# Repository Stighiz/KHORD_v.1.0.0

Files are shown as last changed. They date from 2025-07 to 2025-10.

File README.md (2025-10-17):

# KHORD_v.1.0.0
KHORD è una tastiera stenografica digitale open-source, a basso costo e personalizzabile, pensata per studenti, scrittori, programmatori e hobbisti, oltre che per professionisti.

FOTO KHORD

Progettata da zero, include un hardware ottimizzato per la stenografia a due mani e un firmware in C per il microcontrollore ESP32-S3, il quale non è supportato dai firmware open-source esistenti (es. QMK).

La repository è organizzata in 4 cartelle:  
- `Hardware/`: schema elettrico, layout PCB, modello 3D del case, file Gerber  
- `Software/`: firmware in C (ESP-IDF) per gestione matrice, debouncing, protocollo GeminiPR, comunicazione USB con Plover 4.0.1
- `Case/`: file per la stampa 3D del case 
- `Documentazione/`: presentazione di KHORD + relazione tecnica con descrizione dettagliata dell'intero progetto e appendici sull'organizzazione dei file hardware e software, sui i metodi principali contenuti e sulle loro funzioni. 

A [questo link](https://www.typination.com/ploversteno) è disponibie un dizionario da inglese a steno, utile per imparare gli accordi stenografici.

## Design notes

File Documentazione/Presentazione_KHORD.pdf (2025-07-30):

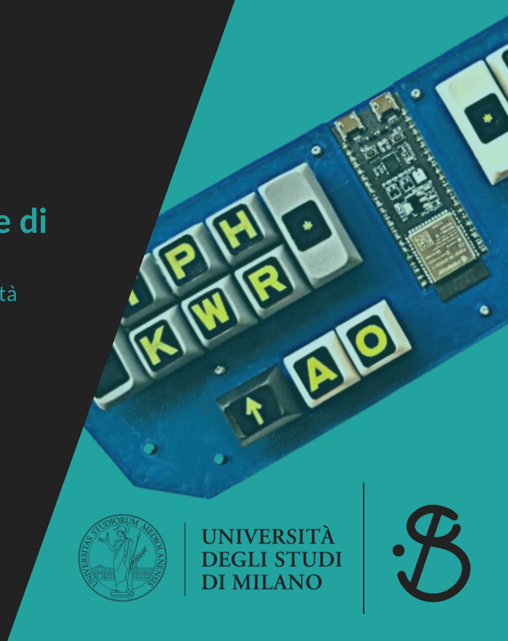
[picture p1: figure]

## KHORD: Progettazione e Realizzazione di una Tastiera Stenografica Digitale

Dipartimento di Informatica ”Giovanni degli Antoni”, Universita`

degli Studi di Milano

Valeria Stighezza e Marco Barbaro

Luglio 2025

## Indice

1 Introduzione

- Introduzione
- Progettazione Hardware
- Progettazione Software
- Analisi e Conclusioni

## Stenografia e Tastiere Stenografiche

1 Introduzione

Le Tastiere Stenografiche

- Stenografia = trascrizione testuale in tempo reale
- Tastiera stenografica divisa in: consonanti iniziali / vocali / consonanti finali
- Non tutte le lettere sono presenti (es. C), alcune sono ripetute (es. T)
- Input fonetico tramite accordi: pressione simultanea di piu tasti ( ` | chords)

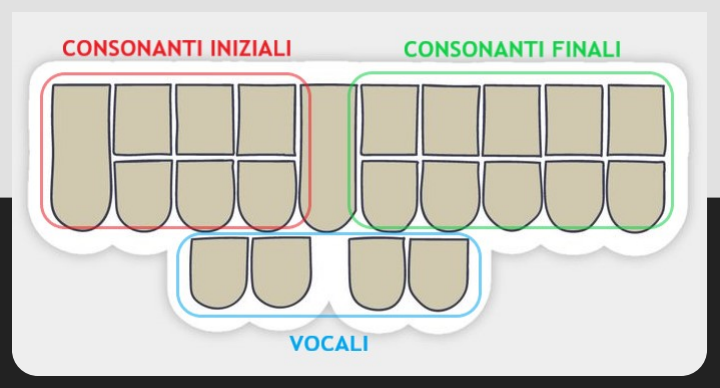
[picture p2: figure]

- Accordi: sillabe o intere parole
- Esempi: ”cat” → KAT, ”chord” → KHORD
- Velocita:` 200+ WPM (al posto di 50-80)

## Tastiere Meccaniche e Obiettivi del Progetto

1 Introduzione

Le Tastiere Meccaniche
- Interruttori meccanici individuali sotto a ogni tasto
- Vantaggi: durata, N-key rollover, anti-ghosting, personalizzazione (es. QMK), facile manutenzione

Obiettivi e Motivazioni del progetto

- Superare limiti di QMK su ESP32-S3 (non compatibile!!)
- Firmware dedicato + hardware su misura
- Tastiera a basso costo e open-source → accessibile e replicabile
- Pensata per chiunque: studenti, programmatori, scrittori, professionisti ...

## Indice

2 Progettazione Hardware

- Introduzione
- Progettazione Hardware
- Progettazione Software
- Analisi e Conclusioni

## Componentistica

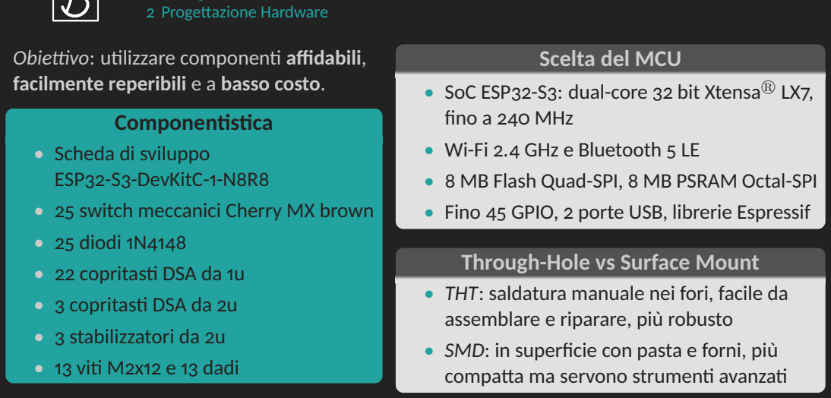
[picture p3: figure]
2 Progettazione Hardware; Obiettivo: utilizzare componenti affidabili, facilmente reperibili e a basso costo.; Componentistica; • Scheda di sviluppo; ESP32-S3-DevKitC-1-N8R8; • 25 switch meccanici Cherry MX brown; • 25 diodi 1N4148; • 22 copritasti DSA da 1u; • 3 copritasti DSA da 2u; • 3 stabilizzatori da 2u; • 13 viti M2x12 e 13 dadi; Scelta del MCU; fino a 240 MHz; • Wi-Fi 2.4 GHz e Bluetooth 5 LE; Through-Hole vs Surface Mount; assemblare e riparare, piu robusto `; compatta ma servono strumenti avanzati

- SoC ESP32-S3: dual-core 32 bit Xtensa® LX7,
- 8 MB Flash Quad-SPI, 8 MB PSRAM Octal-SPI
- Fino 45 GPIO, 2 porte USB, librerie Espressif
- THT: saldatura manuale nei fori, facile da
- SMD: in superficie con pasta e forni, piu`

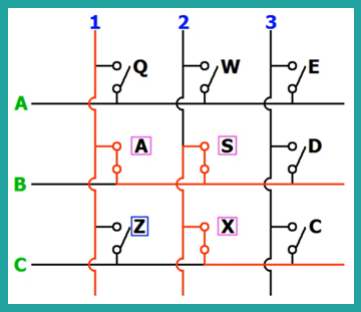
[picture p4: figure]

## Gestione Affidabile dell’Input

2 Progettazione Hardware

Obiettivo: garantire l’affidabilita della tastiera anche con ` pressioni multiple simultanee.

Ghosting - senza Diodi
- Piu tasti premuti ` | → percorsi elettrici indesiderati
- Il microcontrollore registra tasti mai premuti (es. Z)

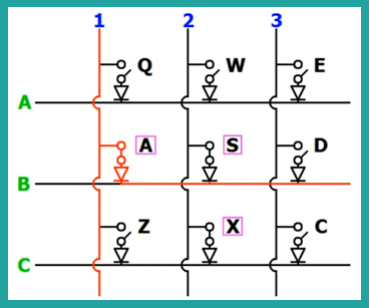
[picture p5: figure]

| Blocking - con Diodi
- Ogni tasto ha un diodo in serie: corrente solo dalla colonna alla riga (no percorsi inversi → no ghosting)
| N-Key Rollover
- Grazie ai diodi, ogni tasto e` indipendente e rilevabile simultaneamente

## Progettazione Circuito Stampato - Schema Elettrico

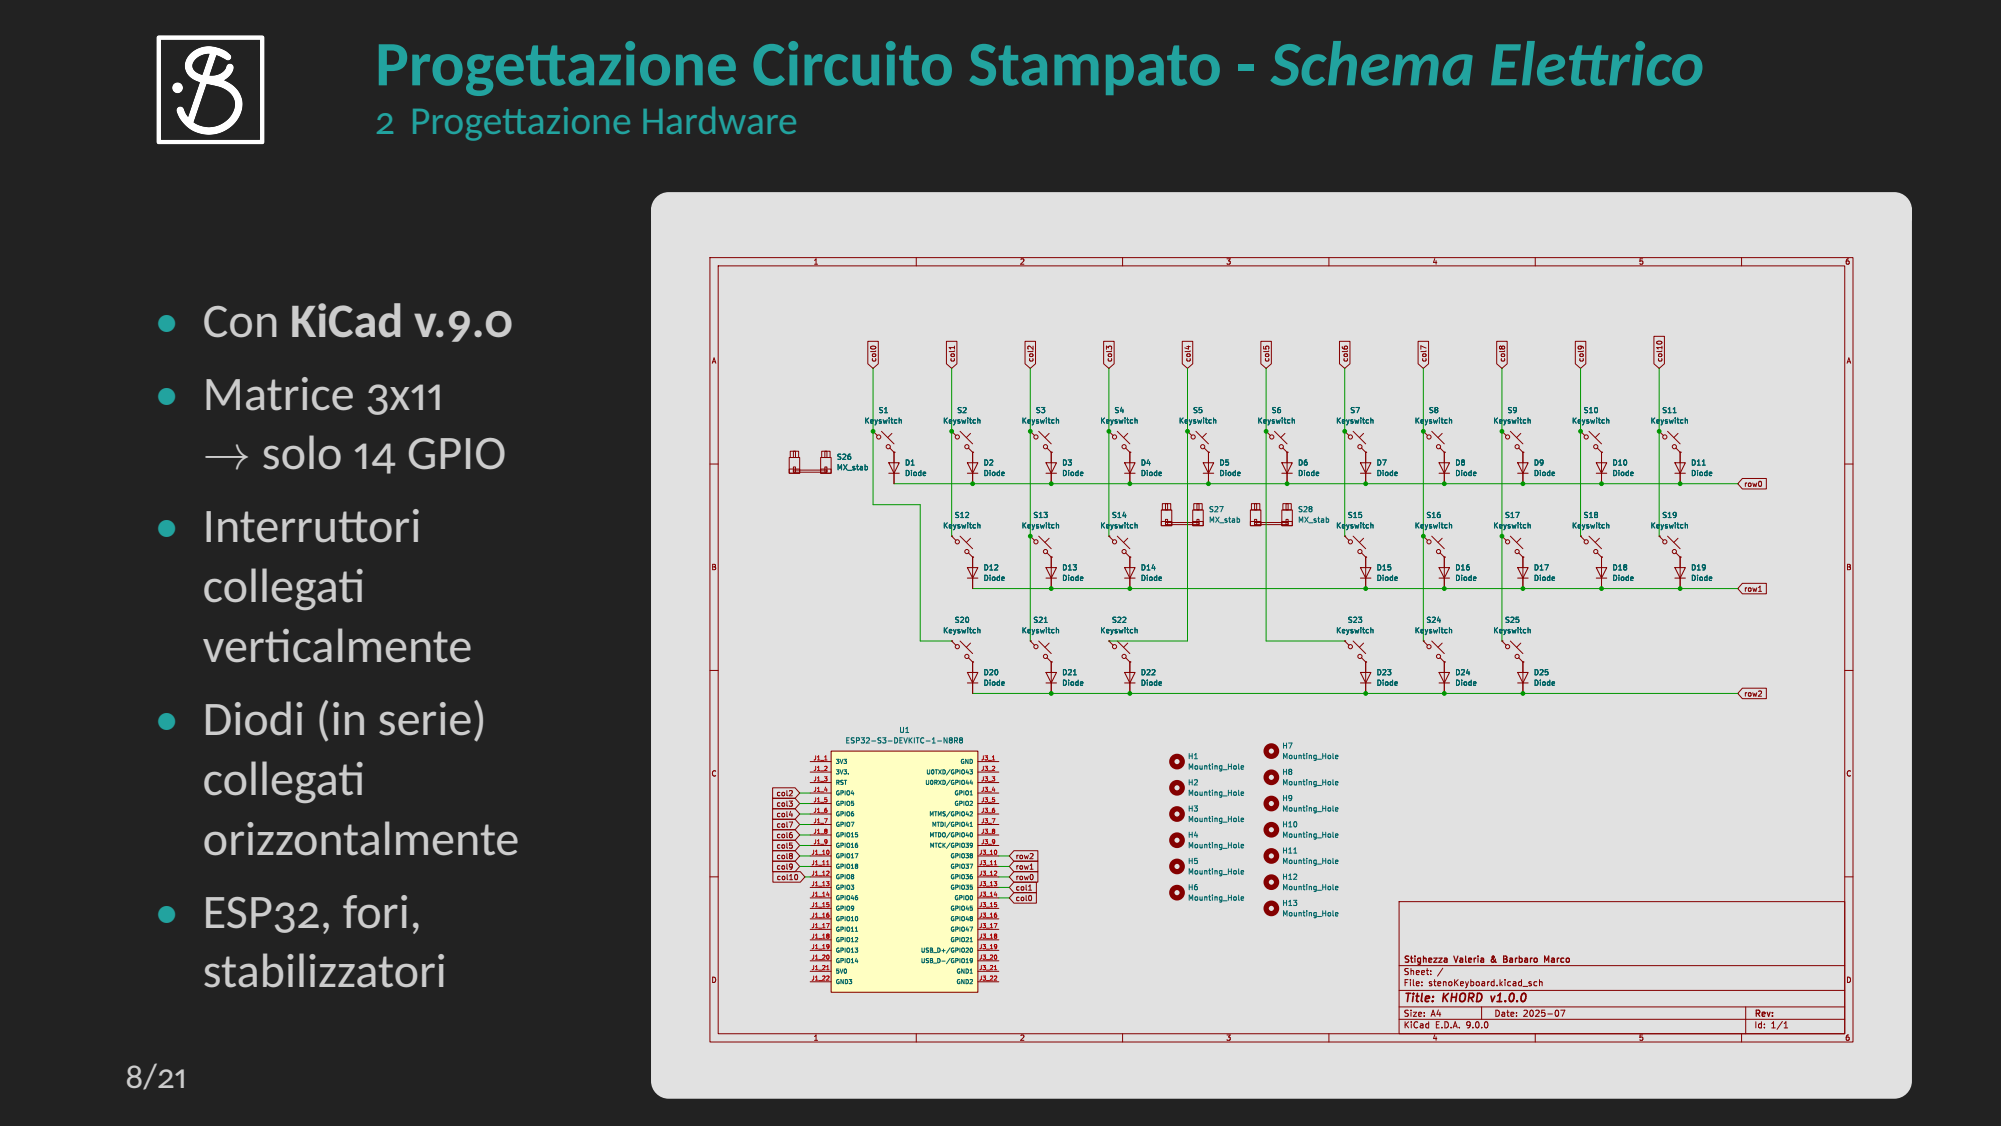
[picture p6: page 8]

## Progettazione Circuito Stampato - Layout

2 Progettazione Hardware

- Interruttori, ESP32 e stabilizzatori su F.Cu; diodi su B.Cu
- Routing: colonne su B.Cu, righe su F.Cu; vias usati per incroci, tracce da 0.5 mm (min. dist. 1 mm), angoli 90° evitati
- Serigrafia include logo personalizzato
- Zone di rame <no net>: migliorano dissipazione, isolamento e robustezza

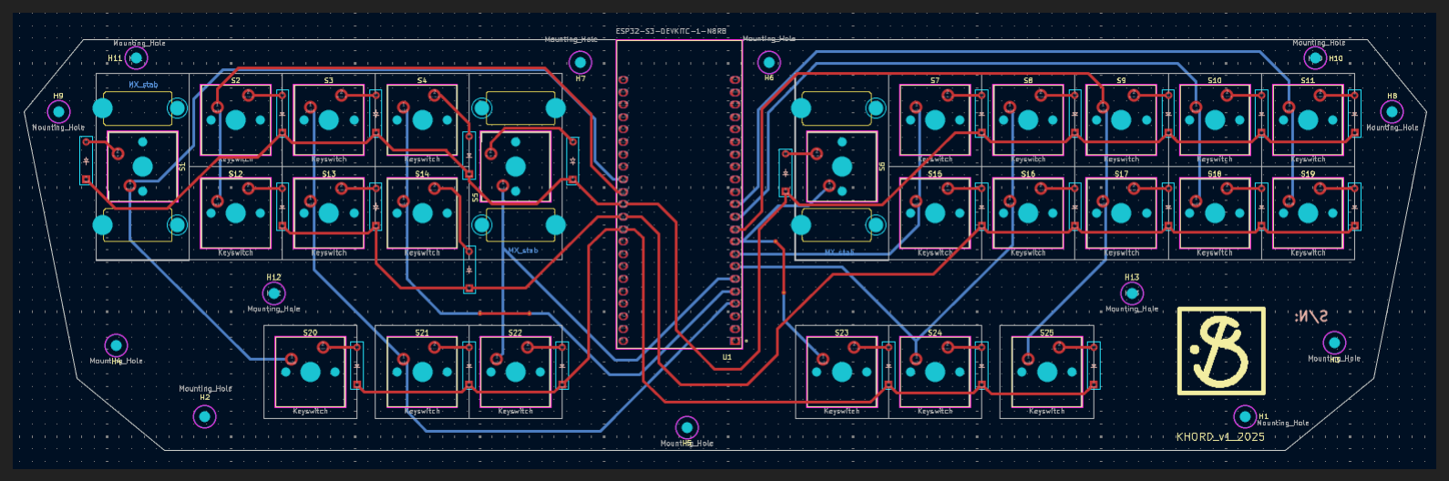
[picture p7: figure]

## Progettazione Circuito Stampato - Modello 3D

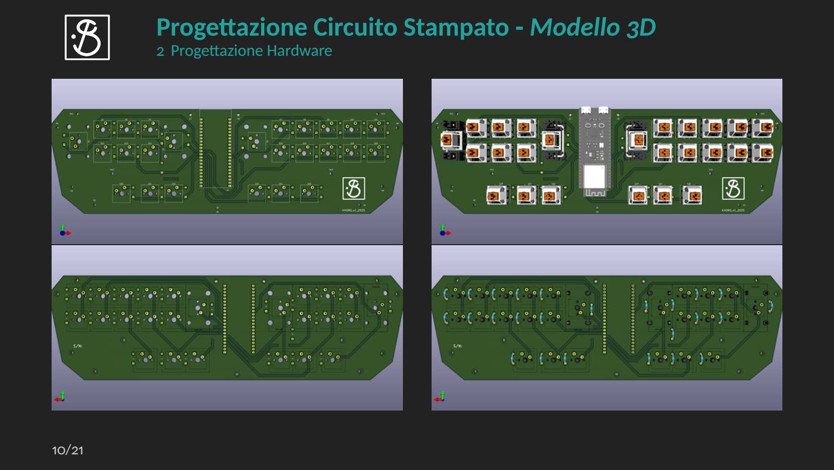
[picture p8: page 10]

2 Progettazione Hardware

## Produzione PCB e Case 3D

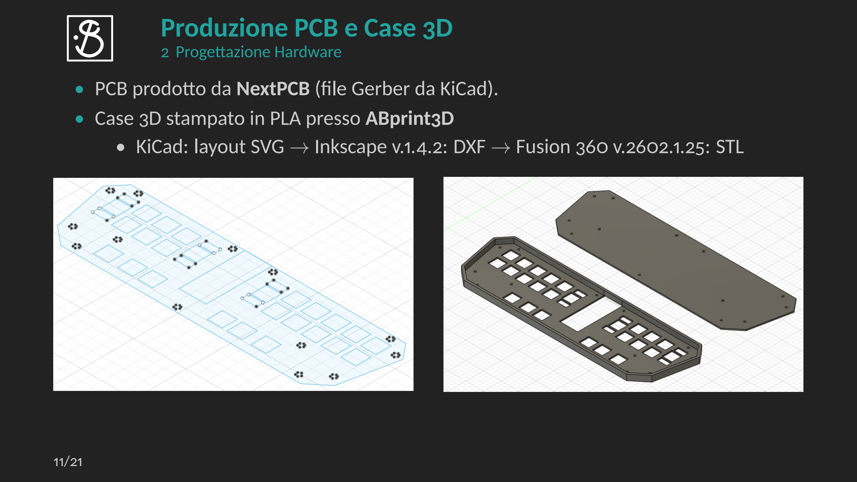
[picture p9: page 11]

2 Progettazione Hardware

- PCB prodotto da NextPCB (file Gerber da KiCad).
- Case 3D stampato in PLA presso ABprint3D
- KiCad: layout SVG → Inkscape v.1.4.2: DXF → Fusion 360 v.2602.1.25: STL

## Saldatura dei Componenti (THT)

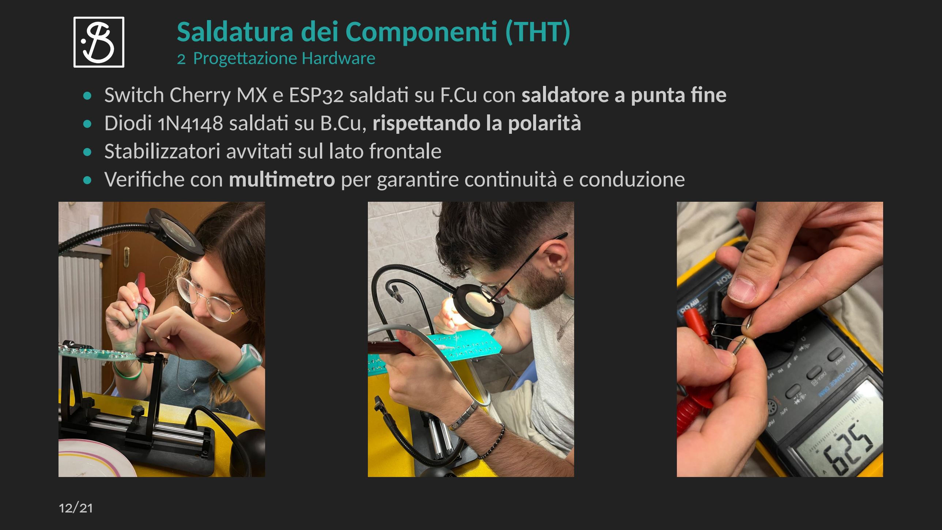
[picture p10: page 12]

2 Progettazione Hardware

- Switch Cherry MX e ESP32 saldati su F.Cu con saldatore a punta fine
- Diodi 1N4148 saldati su B.Cu, rispettando la polarita`
- Stabilizzatori avvitati sul lato frontale
- Verifiche con multimetro per garantire continuita e conduzione `

## Montaggio Finale e Risultato

2 Progettazione Hardware

- Con viti M2 e dadi: top case con PCB + bottom case
- Test funzionali completati: stabilita meccanica e circuitale `

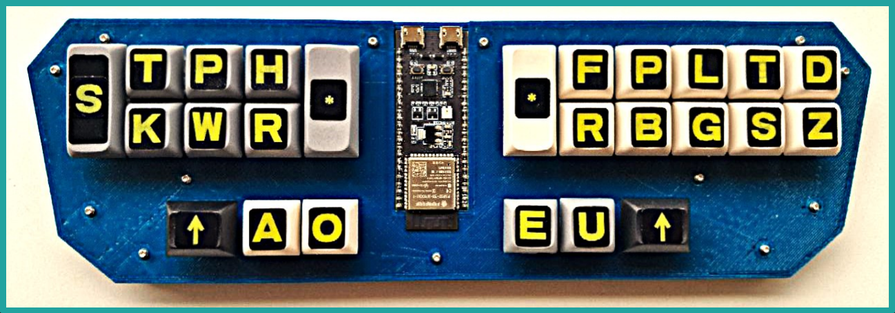
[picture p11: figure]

## Indice

3 Progettazione Software

- Introduzione
- Progettazione Hardware
- Progettazione Software
- Analisi e Conclusioni

## Pipeline di Sviluppo Firmware

3 Progettazione Software

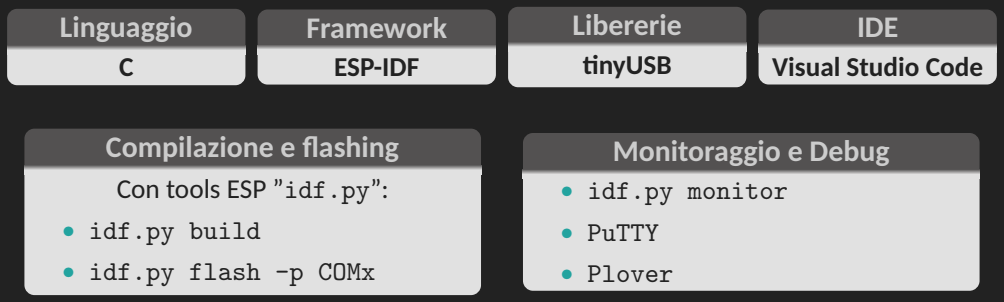
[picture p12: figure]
Linguaggio; Framework; ESP-IDF; Libererie; tinyUSB; IDE; Visual Studio Code; Compilazione e flashing; Con tools ESP ”idf.py”:; • idf.py build; • idf.py flash -p COMx; Monitoraggio e Debug; • idf.py monitor; • PuTTY; • Plover

## Scansione della Matrice e Debouncing

3 Progettazione Software

- Matrice fisica 3x11 gestita via GPIO
- Rappresentata come array di uint16 t dove ogni cella e una riga e ogni bit ` | e`
una colonna
- Doppia matrice:
- RAW: stato diretto della tastiera
- FILTRATA: stato stabile post-debounce
- Matrix Scan ogni 3ms
- Innescato da interrupt HW GPTimer
- Deferred work: ISR minimale e gestione nel main
- Debounce software timing-based di 10ms

## Protocollo di Chording e Plover

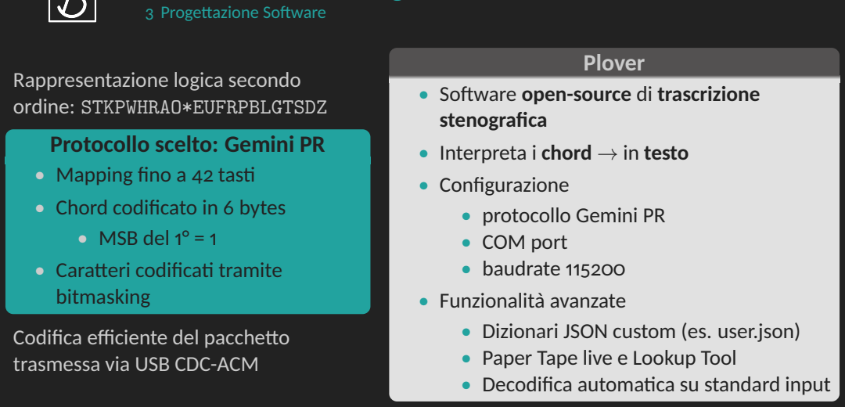
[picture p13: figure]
3 Progettazione Software; Rappresentazione logica secondo; ordine: STKPWHRAO*EUFRPBLGTSDZ; Protocollo scelto: Gemini PR; • Mapping fino a 42 tasti; • Chord codificato in 6 bytes; • MSB del 1° = 1; • Caratteri codificati tramite; bitmasking; Codifica efficiente del pacchetto; trasmessa via USB CDC-ACM; Plover; • Software open-source di trascrizione stenografica; • Interpreta i chord → in testo; • Configurazione; • protocollo Gemini PR; • COM port • baudrate 115200; • Funzionalita avanzate `; • Dizionari JSON custom (es. user.json); • Paper Tape live e Lookup Tool

- Decodifica automatica su standard input

## Indice

4 Analisi e Conclusioni

- Introduzione
- Progettazione Hardware
- Progettazione Software
- Analisi e Conclusioni

## Analisi e Valutazioni

4 Analisi e Conclusioni

Potenza Dissipata

- Inferiore a 0.1 W anche in presenza di input ad alta intensita`

Prestazioni (Tempi di Esecuzione)

- Tscan = 99µs, ogni 3 ms → circa 2.9 ms liberi per le operazioni asincrone
- Ttrasmissione = 520µs → reattivita elevata anche con input intenso `

Costo in e

- Costo Pezzi Utilizzati: 32.24 e
- Costo Totale Acquisto in Blocco: 66.24 e
- + 40 e per il case (il prezzo dipende dalla disponibilita di una stampante 3D) `

## Conclusioni e Sviluppi Futuri

4 Analisi e Conclusioni

Obiettivi raggiunti: tastiera stenografica open-source, economica e personalizzabile → facilmente replicabile da chiunque

Sviluppi futuri:

- Versione wireless → batteria + isolamento antenna + modifiche sw
- Sistema di visualizzazione delle informazioni (display a 7 segmenti o LCD)
- Sistema di retroilluminazione a LED per migliorare visibilita e estetica `
- Aggiunta di layer alternativi
- Gestione della pressione di lunga durata
- Introduzione di macro

# KHORD: Progettazione e Realizzazione di una Tastiera Stenografica Digitale

## Grazie dell’attenzione

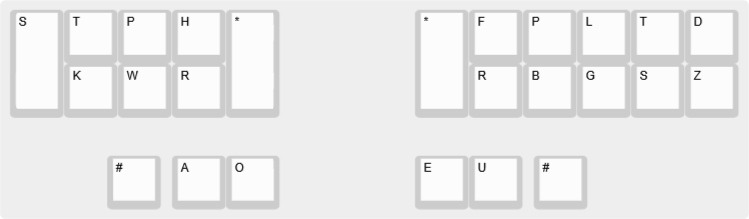
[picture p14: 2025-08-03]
Hardware/layout/layout.png

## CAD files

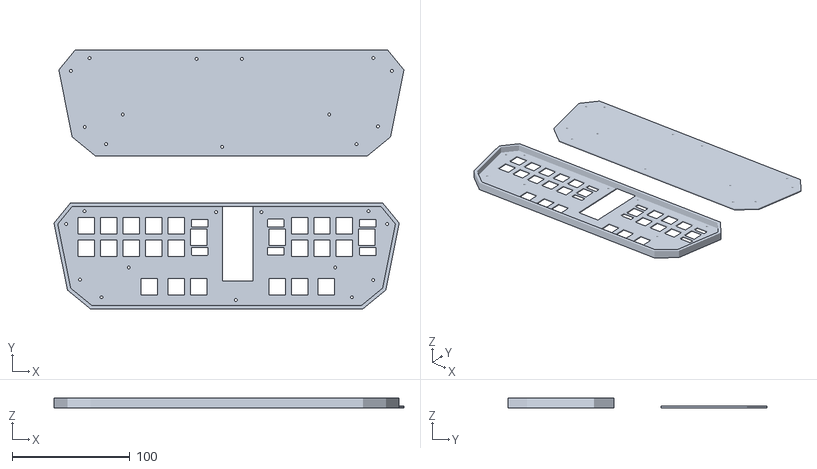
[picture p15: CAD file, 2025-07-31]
Case/KHORD_Case v1.stl
297.1 x 219.8 x 8.10

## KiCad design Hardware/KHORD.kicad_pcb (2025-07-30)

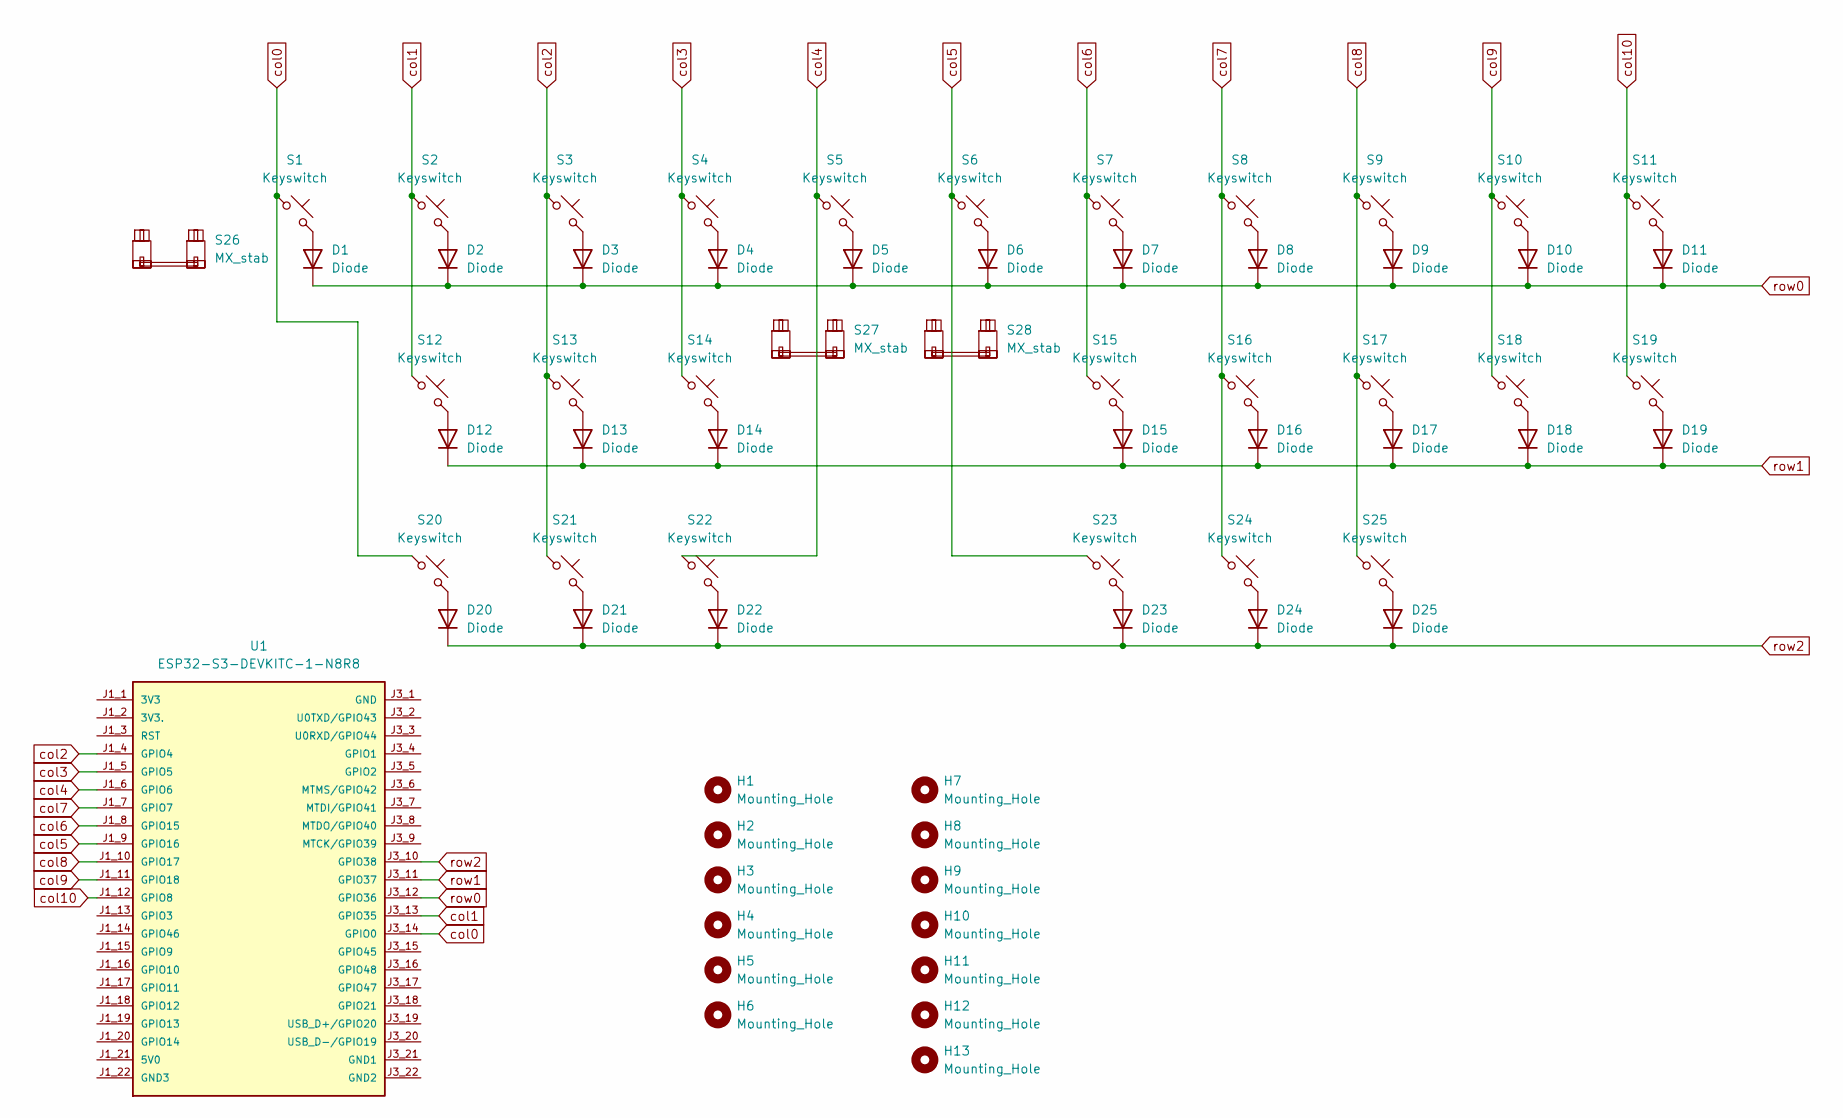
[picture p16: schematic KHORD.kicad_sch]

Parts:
D1, D2, D3, D4, D5, D6, D7, D8, D9, D10, D11, D12, D13, D14, D15, D16, D17, D18, D19, D20, D21, D22, D23, D24, D25: Diode; Diode_DO-35
H1, H2, H3, H4, H5, H6, H7, H8, H9, H10, H11, H12, H13: Mounting_Hole; MountingHole_2.2mm_M2
S1, S5, S6: Keyswitch; MX_PCB_2.00u
S2, S3, S4, S7, S8, S9, S10, S11, S12, S13, S14, S15, S16, S17, S18, S19, S20, S21, S22, S23, S24, S25: Keyswitch; MX_PCB_1.00u
S26, S27, S28: MX_stab; STAB_MX_2u
U1: ESP32-S3-DEVKITC-1-N8R8; ESP32-S3-DEVKITC-1-N8R8_largePad

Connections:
unnamed: D1.2 (A), S1.2
unnamed: D2.2 (A), S2.2
unnamed: D3.2 (A), S3.2
unnamed: D4.2 (A), S4.2
unnamed: D5.2 (A), S5.2
unnamed: D6.2 (A), S6.2
unnamed: D7.2 (A), S7.2
unnamed: D8.2 (A), S8.2
unnamed: D9.2 (A), S9.2
unnamed: D10.2 (A), S10.2
unnamed: D11.2 (A), S11.2
unnamed: D12.2 (A), S12.2
unnamed: D13.2 (A), S13.2
unnamed: D14.2 (A), S14.2
unnamed: D15.2 (A), S15.2
unnamed: D16.2 (A), S16.2
unnamed: D17.2 (A), S17.2
unnamed: D18.2 (A), S18.2
unnamed: D19.2 (A), S19.2
unnamed: D20.2 (A), S20.2
unnamed: D21.2 (A), S21.2
unnamed: D22.2 (A), S22.2
unnamed: D23.2 (A), S23.2
unnamed: D24.2 (A), S24.2
unnamed: D25.2 (A), S25.2
col0: S1.1, S20.1, U1.J3_14 (GPIO0)
col1: S2.1, S12.1, U1.J3_13 (GPIO35)
col2: S3.1, S13.1, S21.1, U1.J1_4 (GPIO4)
col3: S4.1, S14.1, U1.J1_5 (GPIO5)
col4: S5.1, S22.1, U1.J1_6 (GPIO6)
col5: S6.1, S23.1, U1.J1_9 (GPIO16)
col6: S7.1, S15.1, U1.J1_8 (GPIO15)
col7: S8.1, S16.1, S24.1, U1.J1_7 (GPIO7)
col8: S9.1, S17.1, S25.1, U1.J1_10 (GPIO17)
col9: S10.1, S18.1, U1.J1_11 (GPIO18)
col10: S11.1, S19.1, U1.J1_12 (GPIO8)
row0: D1.1 (K), D2.1 (K), D3.1 (K), D4.1 (K), D5.1 (K), D6.1 (K), D7.1 (K), D8.1 (K), D9.1 (K), D10.1 (K), D11.1 (K), U1.J3_12 (GPIO36)
row1: D12.1 (K), D13.1 (K), D14.1 (K), D15.1 (K), D16.1 (K), D17.1 (K), D18.1 (K), D19.1 (K), U1.J3_11 (GPIO37)
row2: D20.1 (K), D21.1 (K), D22.1 (K), D23.1 (K), D24.1 (K), D25.1 (K), U1.J3_10 (GPIO38)

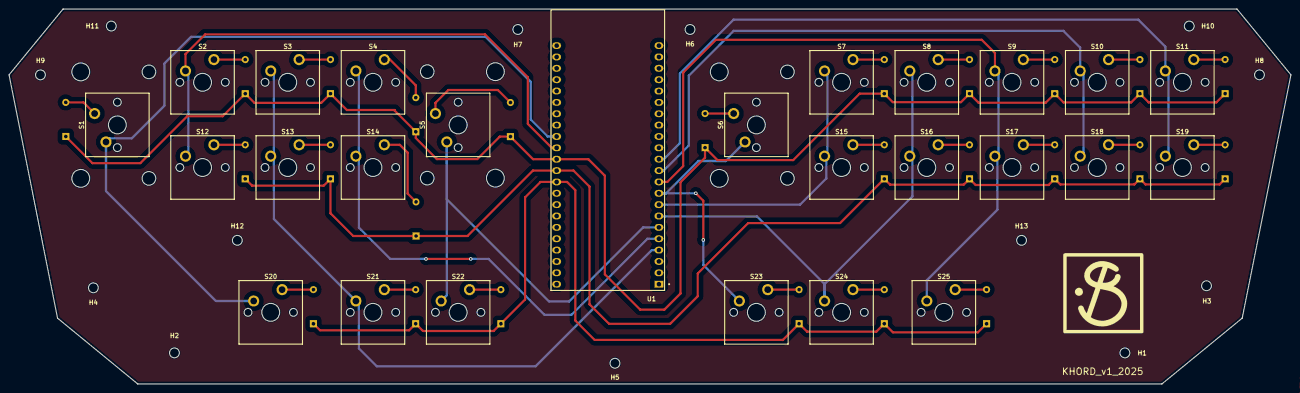
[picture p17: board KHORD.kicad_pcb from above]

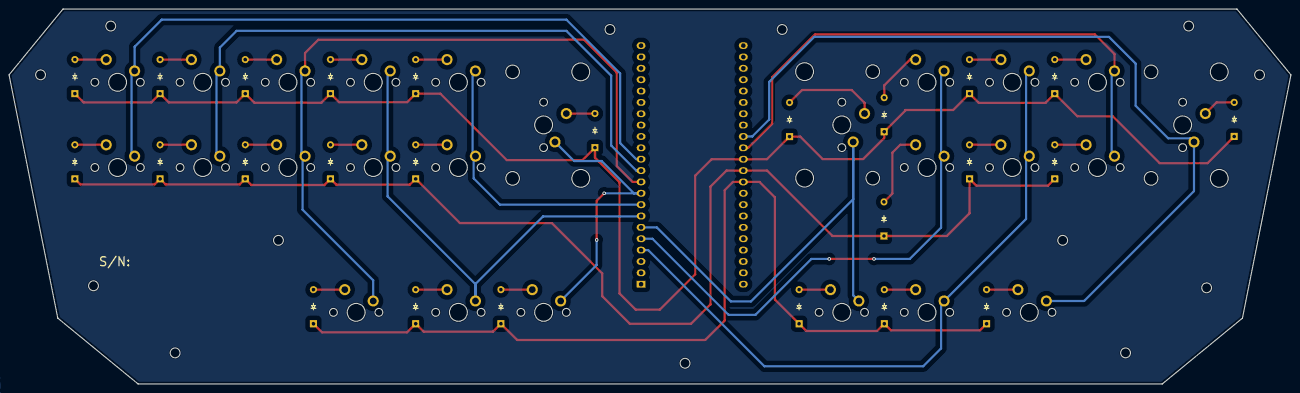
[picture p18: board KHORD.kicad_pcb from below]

Board: 2 copper layers, 286.6 x 83.8 mm, 67 parts (25 on the bottom side), 39 nets.

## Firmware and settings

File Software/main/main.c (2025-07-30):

#include <stdio.h>
#include <stdbool.h>

#include "matrix.h"
#include "config.h"
#include "keyboard.h"
#include "timer.h"
#include "usb.h"

//ESP-IDF
#include "sdkconfig.h"
#include "freertos/FreeRTOS.h"
#include "freertos/task.h"
#include "esp_log.h"
#include "driver/gpio.h"

//Delay
#include "esp_rom_sys.h"

static const char *TAG = "main";

void app_main(void)
{
    ESP_LOGI(TAG, "-----------------------------------------------");
    ESP_LOGI(TAG, "Configuring TinyUSB");
    usb_init();
    
    vTaskDelay(10);

    ESP_LOGI(TAG, "-----------------------------------------------");
    ESP_LOGI(TAG, "Starting MATRIX_INIT");
    matrix_init();

    vTaskDelay(10);

    ESP_LOGI(TAG, "-----------------------------------------------");
    ESP_LOGI(TAG, "Starting TIMER_SETUP");
    timer_setup();

    while(1) 
    {
        if (matrix_scan_requested)
        {
            matrix_scan_requested = false;  // Clear flag
            matrix_task();                  
        }

        //Micro delay to yield the CPU to other processes
        vTaskDelay(1);
    }
}

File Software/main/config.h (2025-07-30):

#pragma once

#include "driver/gpio.h"

#define PRINT_DEBUG 1

#define LOW 0
#define HIGH 1
#define MATRIX_INPUT_PRESSED_STATE 0

#define MATRIX_ROWS 3
#define MATRIX_COLS 11
#define DEBOUNCE 10

#define TIMEOUT_TICKS 0
#define TIMER_RESOLUTION 1000000
#define TIMER_SCAN_DELAY 3000
#define TIMER_COUNT_START 0

#define MATRIX_COL_PINS { GPIO_NUM_0, GPIO_NUM_35, GPIO_NUM_4, GPIO_NUM_5, GPIO_NUM_6, GPIO_NUM_16, GPIO_NUM_15, GPIO_NUM_7, GPIO_NUM_17, GPIO_NUM_18, GPIO_NUM_8 }
#define MATRIX_ROW_PINS { GPIO_NUM_36, GPIO_NUM_37, GPIO_NUM_38 }

/* COL2ROW, ROW2COL*/
#define DIODE_DIRECTION COL2ROW
